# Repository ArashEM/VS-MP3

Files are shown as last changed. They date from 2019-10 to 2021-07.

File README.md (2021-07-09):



# Introduction

`VS1063` is an audio encoder/decoder from [VLSI solution](http://www.vlsi.fi/en/home.html). Base on VS1063 and STM32F1X, I'd designed a simple MP3 player. 

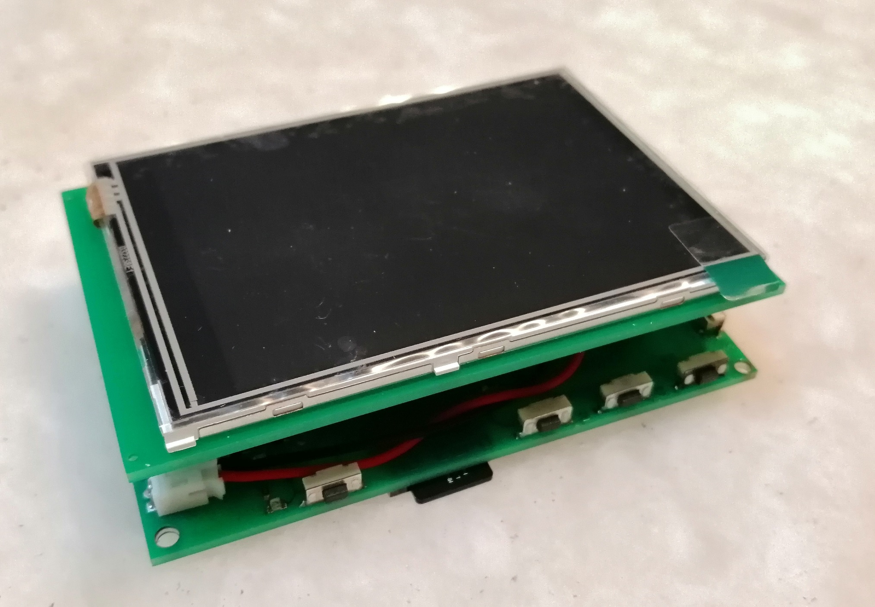
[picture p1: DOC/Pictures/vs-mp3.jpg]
MP3P-OFF


# Specification

Here is list of main element used in my MP3P project:

- `VS1063a` as MP3 / FLAC decoder
- `STM32F103RCT6` as main controller 
- Can be powered from USB and Li-ion battery (without interruption on exchange)
- `TPS62110QRSARQ1`  as switching regulator (3v7 to 3v3)
- `MAX1555EZK` Li-ion battery charger
- `LTC4412ES6` Power Path controller 
- `SDIO` 4bit connection (<u>which only 1bit got working</u>!)
- Header pin for LCD connection (Compatible with Raspberry Pi hats)

# Notes

Here is some important notes about this project

1. <u>There is an issue with SDIO and 4 bit connection</u>. I can **NOT** get 4 bit mode working. So I tried to deal with 1bit mode. The problem show it self when you are decoding **FLAC** format. because of SD card slow interface, music can get slow! 
2. I think I should use pull-ups in SDIO data pins. But I'm not sure and I didn't try it till now!
3. Codes is `FW` directory is simple demo application, which play everything in root directory of SD card.
4. Before any decision about this board, as good friend said: **Check it yourself** !
5. Finally ... Have fun ...

## File hierarchy 
- `FW`: includes Keil/Makefile based source code wihch is generated via `STM32CubeMx` and `FW_F1-V1.8.3`
- `HW`: includes schematic/pcb project 
  - `main`: MP3 player main board 
  - `dtr`: LCD and touch screen daughter board
- `DOC`: includes general documents about this project (e.g. datasheets and ...)
- `BOX`: includes related files for box and packaging

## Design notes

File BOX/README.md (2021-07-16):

# Introduction

Idea of  box comes from [Arvinpack](https://www.arvinpack.com/product/craft-prepared-box-keshoyi/). 

Their box is not manufactured form proper material. So designed and built something similar to it. (from _Fabriano  paper, 220 g/m2, 50x70_)

## Files

As I'm an electronic engineer so I'd designed box files with **Altium Designer**!

- `box.PcbDoc`: contains box cutout (_Thick_ lines should be cut, _Thin_ lines should be bent)
- `cover.PcbDoc`: contains cover cutout 
- `holder.PcbDoc`: contains board holder cutout

For each one, I've created `pdf` files which must be printed in actual size (`A4` for holder, `A2` for box and cover)

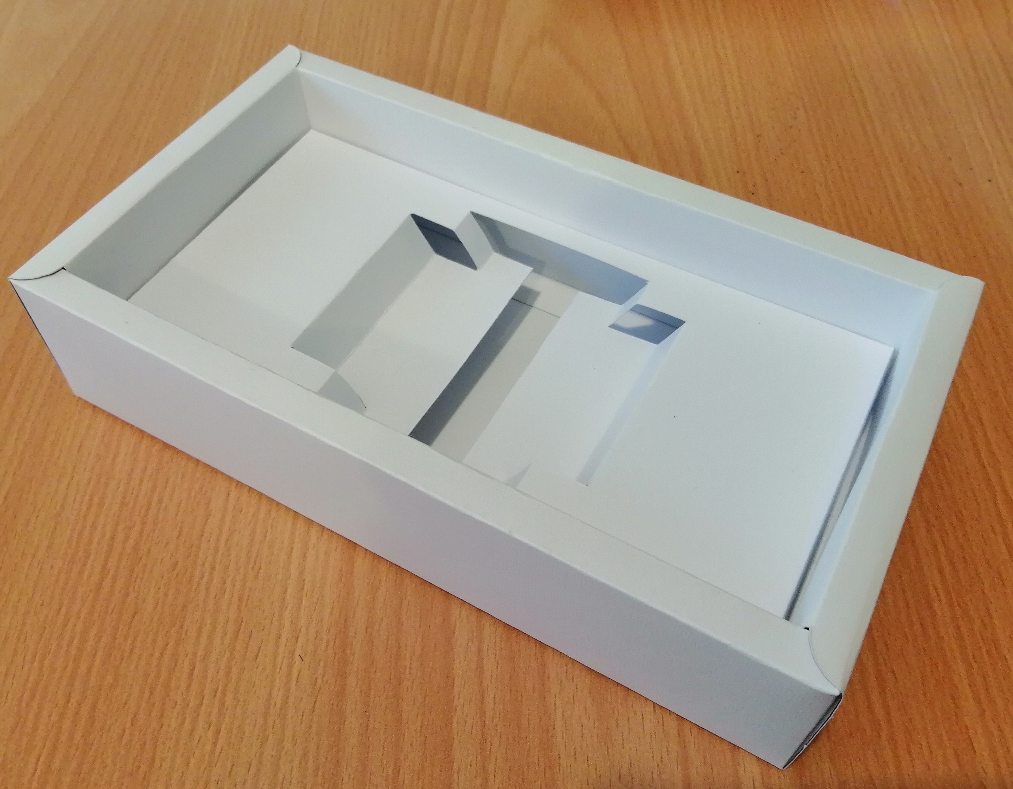
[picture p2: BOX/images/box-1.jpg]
box-1


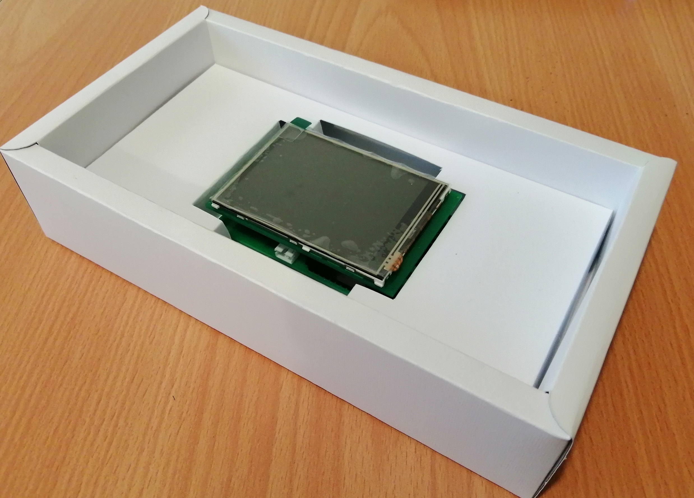
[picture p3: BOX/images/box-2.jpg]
box-2


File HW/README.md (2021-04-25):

# Introduction

This folder contains SCH/PCB files for VS-MP3 project
- `mian`: includes Altium project for main board.
- `dtr`: includes Altium project for LCD/Touch board.

# HW information 

This section includes all information you need about HW platform.  
Like pin assignment, crystal frequency and ...

## General 
- Used micro-controller: `STM32F103RCT6`
  - `HSE` crystal frequency: **8 Mhz**
  - `LSE` crystal frequency: **32.768 Khz**
- LCD controller: `ili9341` / `ili9486`
- Touch screen controller: `xpt2046`
- `VS1063a` crystal frequency: **12.288 Mhz**

## µC Pin assignment

Pin names are according to `STM32F103xC` datasheet, **Table 5**
- `Pin name`: came from micro-controller datasheet
- `Alias in Code`: In order to access a pin via `STM32 HAL GPIO API` you need `PORT` and `PIN`
  - `PORT` is the name in `Alias in Code` column appended to `_GPIO_Port`. (e.g. if Alias is `LED`, it's **port** name will be `LED_GPIO_Port`)
  - `PIN` is name in `Alias in Code` column appended to `_Pin`. (e.g. if Alias is `LED`, it's **pin** name will be `LED_Pin`)
  - As full example, we can toggle LED via `HAL_GPIO_TogglePin(LED_GPIO_Port,LED_Pin);`
- `Peripheral`: which peripheral is used via this pin 
- `Direction`: Pin direction and driver/input type
  - `OUT/PP`: push-pull output driver
  - `IN/PP`: pulled-up input
  - `IN/A`: analog input
  - `OUT/A`: analog output
  - `IN/AF`: input alternative function
  - `OUT/AF`: output alternative function
- `Description`: Some note about this pin (Active high/low, ...)

| Pin name  	| Alias in Code | Peripheral 		| Direction | Description 											|
| ---| ---| ---| ---| ---|
| `PC13` 	| `CHG`			| `GPIO`			| `IN/PP`	| `CHG` pin of `MAX1555` 								|
| `PC0` 	| `ADC_BAT`		| `ADC1_IN10`		| `IN/A`	| Analog battery voltage equal to `0.28 x V-BAT` 		|
| `PC1` 	| `KEY1`		| `GPIO`			| `IN/PP`	| Push button 1 (`S3`) 									|
| `PC2`			| `KEY2`		| `GPIO`			| `IN/PP`	| Push button 2 (`S4`)									|
| `PC3`			| `KEY3`		| `GPIO`			| `IN/PP`	| Push button 3 (`S5`)									|
| `PA0`			| `KEY4`		| `GPIO`			| `IN/PP`	| Push button 4 (`S6`)									|
| `PA1`			| `LED`			| `GPIO`			| `OUT/PP`	| Green LED (`D6`)  									|
| `PA4`			| `VDAC`		| `DAC_OUT1`		| `OUT/A`	| Analog output (`HDR-PIN12`)							|
| `PA15`		| `PWR_EXT`		| `GPIO`			| `OUT/PP`	| Enable `3v3_EXT` supply in `HDR-PIN1`/`HDR-PIN17`		|
| `PB4`			| `REG_PG`		| `GPIO`			| `IN/PP`	| `PG` pin of `TPS62110QRSARQ1`							|
| `PB5`			| `REG_LBO`		| `GPIO`			| `IN/PP`	| `LBO` pin of `TPS62110QRSARQ1` (`LBI = 0.35 x V-BAT`)	|
| `PB8`			| `REG_SYNC`	| `GPIO`			| `OUT/PP`	| `SYNC` pin of `TPS62110QRSARQ1` (Optional connection)	|
| `PB9`			| `VBUS`		| `GPIO`			| `IN`		| Detect power on USB connector (`VBUS = 0.63 x V-USB`)	|
| `PC4`			| `xCS`			| `GPIO`			| `OUT/PP`	| `xCS` pin of `VS1063a`								|
| `PC5`			| `xDCS`		| `GPIO`			| `OUT/PP`	| `xDCS` pin of `VS1063a`								|
| `PB0`			| `DREQ`		| `GPIO/EXTI0_IRQn`	| `IN`		| `DREQ` pin of `VS1063a`								|
| `PB1`			| `xRST`		| `GPIO`			| `OUT/PP`	| `DREQ` pin of `VS1063a`								|
| `PA5`			| `SPI1_SCK`	| `SPI1/SCK`		| `OUT/AF`	| `SCLK` pin of `VS1063a`								|
| `PA6`			| `SPI1_MISO`	| `SPI1/MISO`		| `IN/AF`	| `SO` pin of `VS1063a`									|
| `PA7`			| `SPI1_MOSI`	| `SPI1/MOSI`		| `OUT/AF`	| `SI` pin of `VS1063a`									|
| `PB10`		| `LCD_DCX`		| `GPIO`			| `OUT/PP`	| `DCX` pin of `ili9341`(`HDR-PIN15`)					|
| `PB12`		| `LCD_CS`		| `GPIO/SPI2-NCS0`	| `OUT/PP`	| `CS` pin of `ili9341` (`HDR-PIN24`)					|
| `PC6`			| `LCD_RSTN`	| `GPIO`			| `OUT/PP`	| `RSTN` pin of `ili9341` (`HDR-PIN13`)					|
| `PB11`		| `TP_CS`		| `GPIO/SPI2-NCS1`	| `OUT/PP`	| `CS` pin of `xpt2046` (`HDR-PIN26`)					|
| `PC7`			| `TP_IRQ`		| `GPIO/EXTI7_IRQn`	| `IN`		| `IRQ` pin of `xpt2046` (`HDR-PIN11`)					|
| `PA8`			| `BL_PWM`		| `GPIO`			| `OUT/PP`	| Backlight PWM for LCD (`HDR-PIN7`)					|
| `PA13`		| `SWDIO`		| `SYSTEM`			| `N.A.`	| `SWDIO` pin of `STM32F103RCT6`						|
| `PA14`		| `SWCLK`		| `SYSTEM`			| `N.A.`	| `SWCLK` pin of `STM32F103RCT6`						|
| `PB3`			| `SD_CD`		| `GPIO`			| `IN/PP`	| SD card detect pin 									|
| `PC8`			| `SDIO_D0`		| `SDIO/D0`			| `AF`		| `D0` pin of SD card (SDIO works on in `1bit` mode)	|
| `PC9`			| `SDIO_D1`		| `SDIO/D1`			| `AF`		| `D1` pin of SD card	(**Not working yet**)			|
| `PC10`		| `SDIO_D2`		| `SDIO/D2`			| `AF`		| `D2` pin of SD card	(**Not working yet**)			|
| `PC11`		| `SDIO_D3`		| `SDIO/D3`			| `AF`		| `D3` pin of SD card	(**Not working yet**)			|
| `PC12`		| `SDIO_CK`		| `SDIO/CK`			| `OUT/AF`	| `CLK` pin of SD card									|
| `PD2`			| `SDIO_CMD`	| `SDIO/CMD`		| `OUT/AF`	| `CMD` pin of SD card									|
| `PB13`		| `SPI2_SCK`	| `SPI2/SCK`		| `OUT/AF`	| `SPI/CLK` for `ili9341`/`xpt2046` (`HDR-PIN23`)		|
| `PB15`		| `SPI2_MOSI`	| `SPI2/MOSI`		| `OUT/AF`	| `SPI/MOSI` for `ili9341`/`xpt2046` (`HDR-PIN19`)		|
| `PB14`		| `SPI2_MISO`	| `SPI2/MISO`		| `IN/AF`	| `SPI/MISO` for `ili9341`/`xpt2046` (`HDR-PIN21`)		|
| `PB6`			| `I2C1_SCL`	| `I2C1/SCL`		| `OUT/AF`	| `I2C/SCL` with 4.7k pull-up (`HDR-PIN5`)				|
| `PB7`			| `I2C1_SDA`	| `I2C1/SDA`		| `AF`		| `I2C/SDA` with 4.7k pull-up (`HDR-PIN3`)				|
| `BOOT0`		| `N.A.`		| `SYSTEM`			| `N.A.`	| pulled down to `GND` via 10K							|
| `PB2 (BOOT1)`	| `N.A.`		| `SYSTEM`			| `N.A.`	| pulled down to `GND` via 10K							|
| `PA2`			| `USART2_TX`	| `USART2/TX`		| `OUT/AF`	| optional connection for `RX` pin of `VS1063a`			|
| `PA3`			| `USART2_RX`	| `USART2/RX`		| `IN/AF`	| optional connection for `TX` pin of `VS1063a`			|
| `PA9`			| `USART1_TX`	| `USART1/TX`		| `OUT/AF`	| USART/Tx interface (`HDR-PIN8`)						|
| `PA10`		| `USART1_RX`	| `USART1/TX`		| `IN/AF`	| USART/Rx interface (`HDR-PIN10`)						|

## Header pin assignment

Here is table of `VS1063a` UART pin assignment (**P1**)

| Pin Num.  | Description |
| --- | --- |
|	**1**	| `GND`			|
|	**2**	| `VS-RX`		|
|	**3**	| `VS-TX`		|

Here is table of VS-MP3 main board header pin (**P2**)

| Description  	| Pin		| Pin		| Description 	|
|---|---|---|---|
| `3v3_EXT`		| **1**		|	**2**	| `5V0` (USB only)	|
| `I2C1_SDA`	| **3**		|	**4**	| `5V0` (USB only)	|
| `I2C1_SCL`	| **5**		|	**6**	| `GND`				|
| `BL_PWM` 		| **7**		|	**8**	| `USART1_TX`		|
| `GND`			| **9**		|	**10**	| `USART1_RX`		|
| `TP_IRQ`		| **11**	|	**12**	| `VDAC`			|
| `LCD_RSTN`	| **13**	|	**14**	| `GND`				|
| `LCD_DCX`		| **15**	|	**16**	| `N.C.`			|
| `3v3_EXT`		| **17**	|	**18**	| `N.C.`			|
| `SPI2_MOSI`	| **19**	|	**20**	| `GND`				|
| `SPI2_MISO`	| **21**	|	**22**	| `N.C.`			|
| `SPI2_SCK`	| **23**	|	**24**	| `LCD_CS`			|
| `GND`			| **25**	|	**26**	| `TP_CS`			|

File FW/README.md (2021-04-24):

# Introduction

This folder contains `VS-MP3P` firmware.  
In order to build this firmware you need at least one of following items

## Keil 
You need `Keil µVision V5.16.0.0` installed.
1. `git clone git@github.com:ArashEM/VS-MP3.git`
1. open project file in `FW/MDK-ARM/MP3P.uvprojx`
2. press `F7`
3. find hex/axf file in `FW/MDK-ARM/MP3P/MP3P.axf`

## GCC
You need `arm-none-eabi-gcc` and `GNU make` installed. 
1. `git clone git@github.com:ArashEM/VS-MP3.git`
2. `cd FW/ && make all`
3. find hex/bin file in `FW/build/MP3P.hex`

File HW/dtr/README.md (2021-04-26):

# Introduction

This folder contains SCH/PCB files for LCD daughter board 

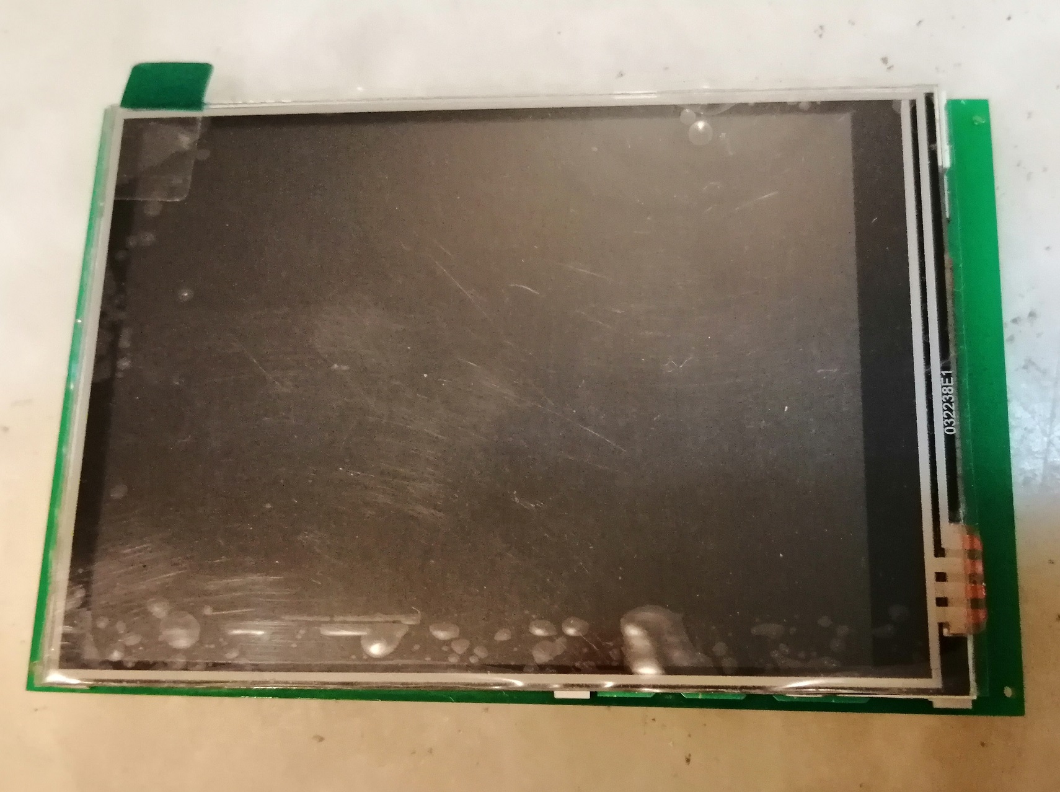
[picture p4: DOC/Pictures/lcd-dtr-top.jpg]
LCD-Top


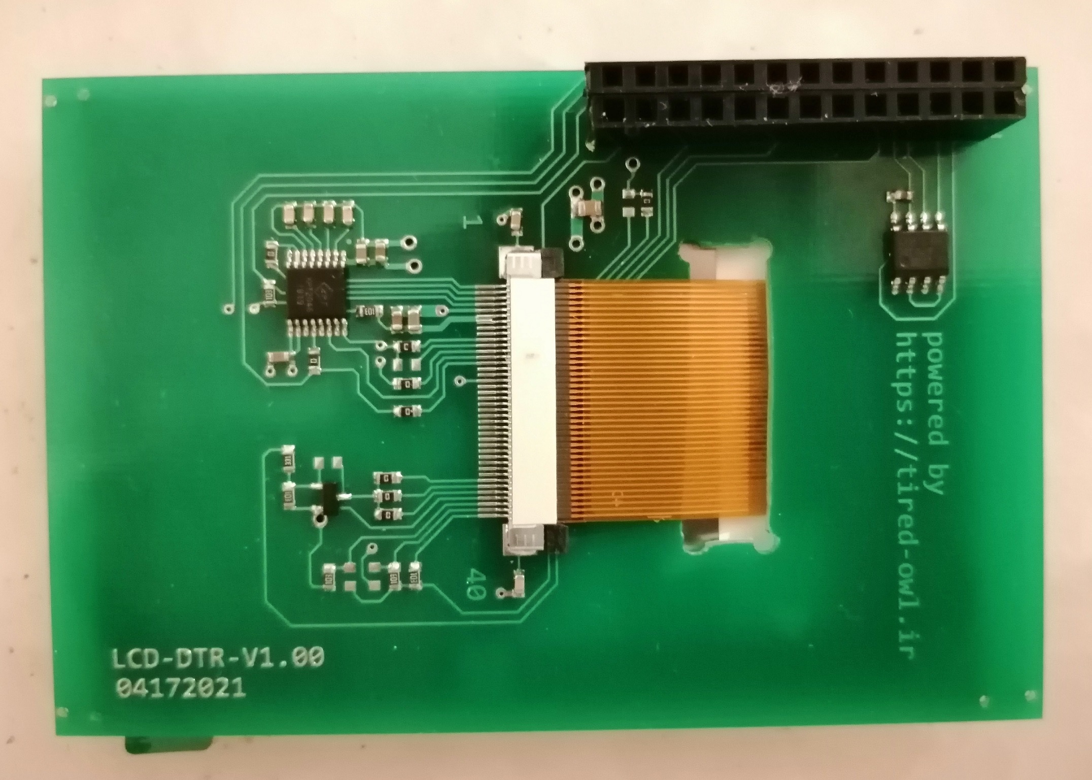
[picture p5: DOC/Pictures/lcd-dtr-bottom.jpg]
LCD-Bot


This board contains following items 
- **40pin-FPC** connector which is compatible with following LCDs
  - *ZJY320IT008*: 3.2 inch *240x320* dots matrix TFT LCD module with `ili9341` controller
  - *ZJY350IT006*: 3.5 inch *320x480* dots matrix TFT LCD module with `ili9486` controller
- `xpt2046` touch screen controller (`ADS7843` can be used too)
- `AT24C512C-SSHD-T` eeprom for some permanent information 

# 3.5/3.2 inch LCD support

According to datasheets of *ZJY320IT008* and *ZJY350IT006* they are **NOT** exactly pin-to-pin compatible!
There is a **subtle** difference which is handled in SCH/PCB via `0R` options. 
For simplicity, I just document the difference. 

| Pin			| *ZJY320IT008* function 		| *ZJY350IT006* function 		|
|---|---|---|
| **10** 		| `SCK` (SPI) / `RS` (Parallel)	| `D/CX`(SPI)			 		|
| **11**		| `D/CX`(SPI) / `WR` (Parallel) | `SCK` (SPI) / `RS` (Parallel) |
| **38/39/40**	| `b011` 4-wire / 8-bit / SPI	| `b111` 4-wire SPI				|

This difference is handled via `R9`/`R17`/`R18`/`R19`/`R20`/`R21` in daughter

| Rx 	| *ZJY320IT008* | *ZJY350IT006* |
|---|---|---|
| `R9`	|	`DNP`		|	`10K`		|
| `R17`	|	`10K`		|	`DNP`		|
| `R18`	|	`0R`		|	`DNP`		|
| `R19`	|	`DNP`		|	`0R`		|
| `R20`	|	`DNP`		|	`0R`		|
| `R21`	|	`0R`		|	`DNP`		|

For more information please check `DOC/datasheets/lcd`

# BOM

| Designator 							| 	Quantity	|	Value			|	Footprint	|
|---|---|---|---|
| `C1`,`C2`,`C8`,`C9`,`C10`,`C11`,`C12`	|	**7**		| `100nF`			|	*0603*		|
| `C3`									|	**1**		| `10uF`			|	*0603*		|
| `C4`,`C5`,`C6`,`C7`					|	**4**		| `10nF`			|	*0603*		|
| `C13`									|	**1**		| `10uF`			|	*0805*		|
| `R1`,`R2`,`R7`,`R8`,`R13`,`R17`		|	**6**		| `10K` 			|	*0603*		|
| `R3`,`R4`,`R5`,`R6`,`R18`,`R21`		|	**6**		| `0R`				|	*0603*		|
| `R9`,`R12`							|	**2**		| `10K_DNP`			|	*0603*		|
| `R10`,`R19`,`R20`						|	**3**		| `0R_DNP`			|	*0603*		|
| `R11`									|	**1**		| `330R`			|	*0603*		|
| `R14`,`R15`,`R16`						|	**3**		| `10R`				|	*0603*		|
| `Q1`									|	**1**		| `IRLML2803TRPBF` 	|	*SOT23*		|
| `U1`									|	**1**		| `xpt2046`			| 	*TSSOP16*	|
| `U2`									|	**1**		| `AT24C512C-SSHD-T`|	*8S1_N*		|
| `LCD1`								|	**1**		| `FPC` 			| *40pin-0.5mm*	|
| `P1`									|	**1**		| `HDR2X13`			| *2x13 100mil*	|

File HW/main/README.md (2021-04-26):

# Introduction

Here is *VS-MP3* main board

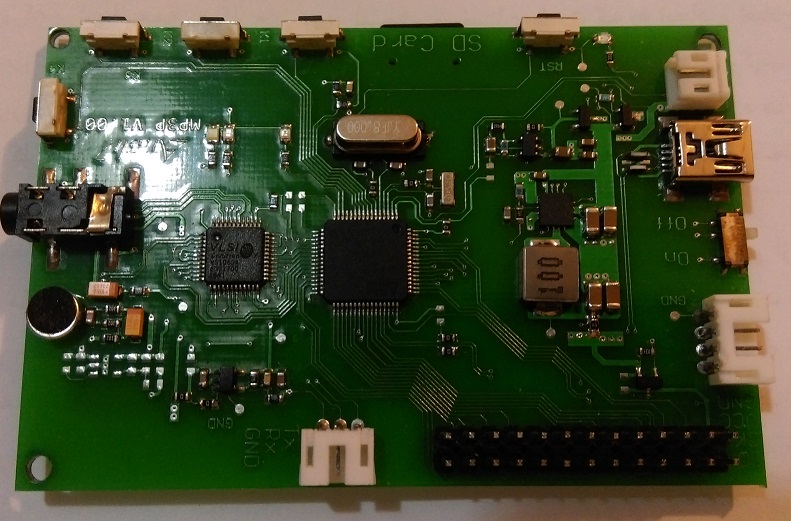
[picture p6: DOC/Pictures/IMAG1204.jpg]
TOP


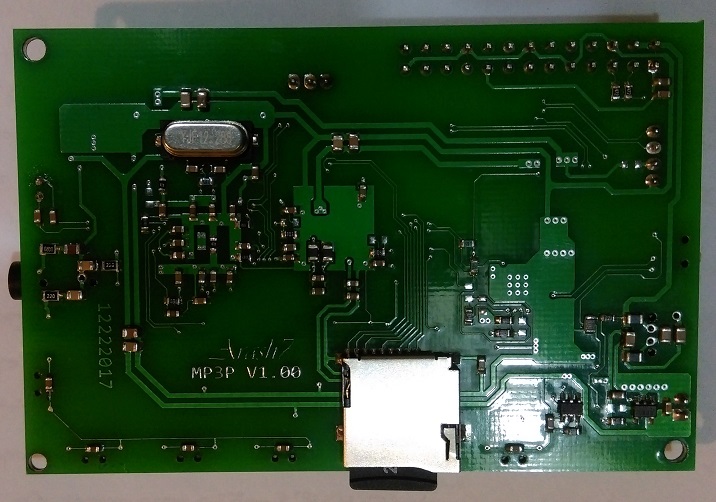
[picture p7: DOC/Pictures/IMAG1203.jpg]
BOT


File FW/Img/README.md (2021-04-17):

# Images

This folder contains original images which are used in projects.

They are used in project source code via **Segger bitmap Converter** with same name. (eg. `moon.c` is bitmap converted of `moon.jpg` )

## specification 

According to LCD interface and color depth, image are converted via _565_ color depth (_Red_: `5 bit`, _Green_: `6 bit` , _Blue_: `5 bit` ) 

## Usage

Here is list of image and there use case in project 

1. `moon.jpg`
2. `tired-owl.png`

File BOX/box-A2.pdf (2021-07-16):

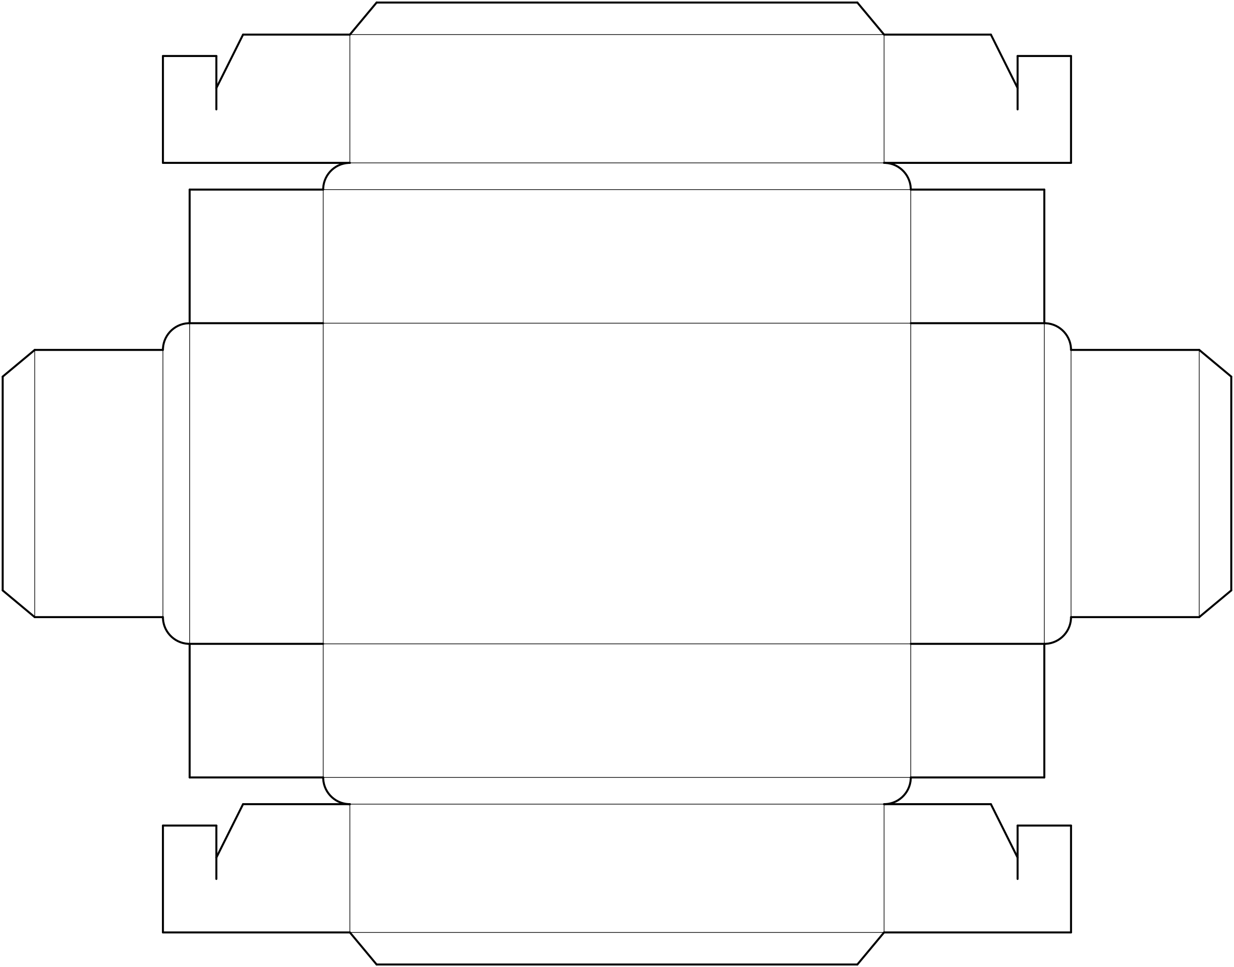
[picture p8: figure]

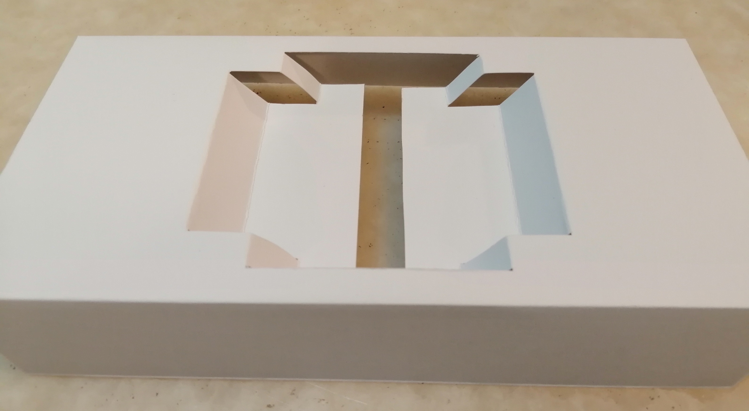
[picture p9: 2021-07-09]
BOX/images/holder-2.jpg

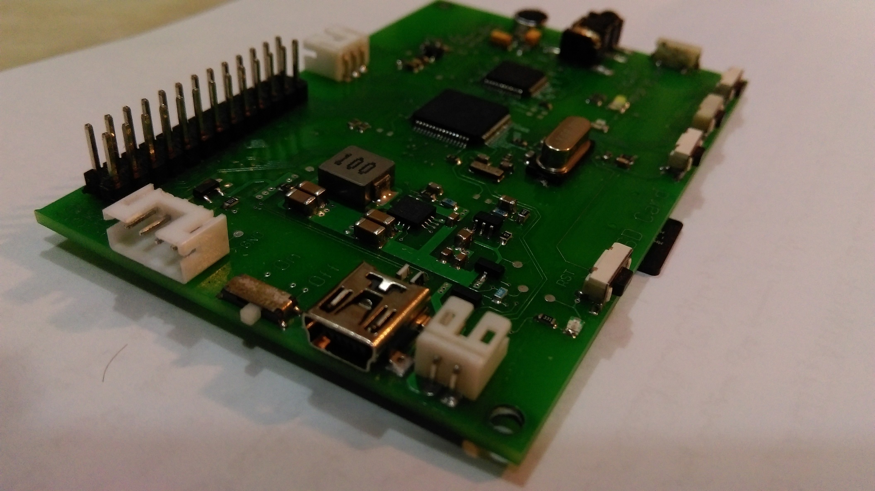
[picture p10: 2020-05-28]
DOC/Pictures/IMAG1206.jpg

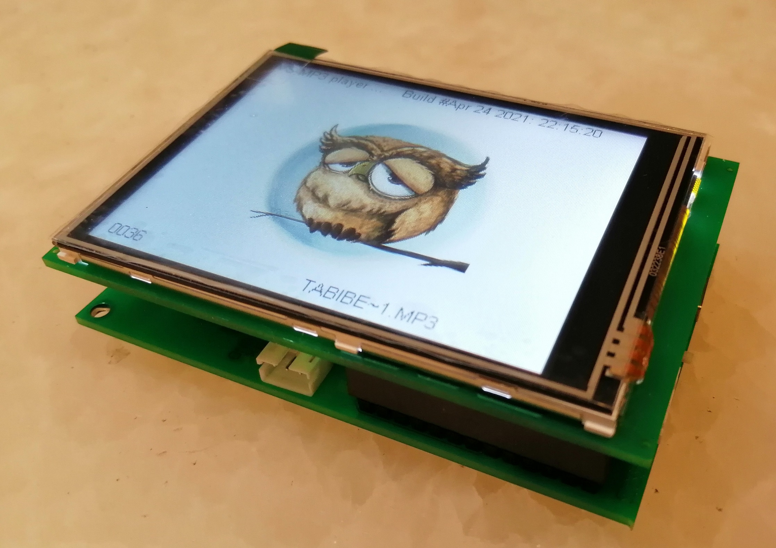
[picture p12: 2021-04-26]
DOC/Pictures/vs-mp3-on.jpg

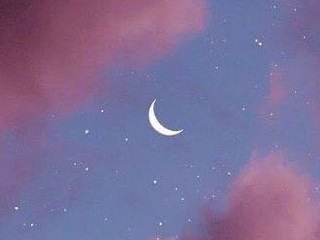
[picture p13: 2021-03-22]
FW/Img/moon.jpg

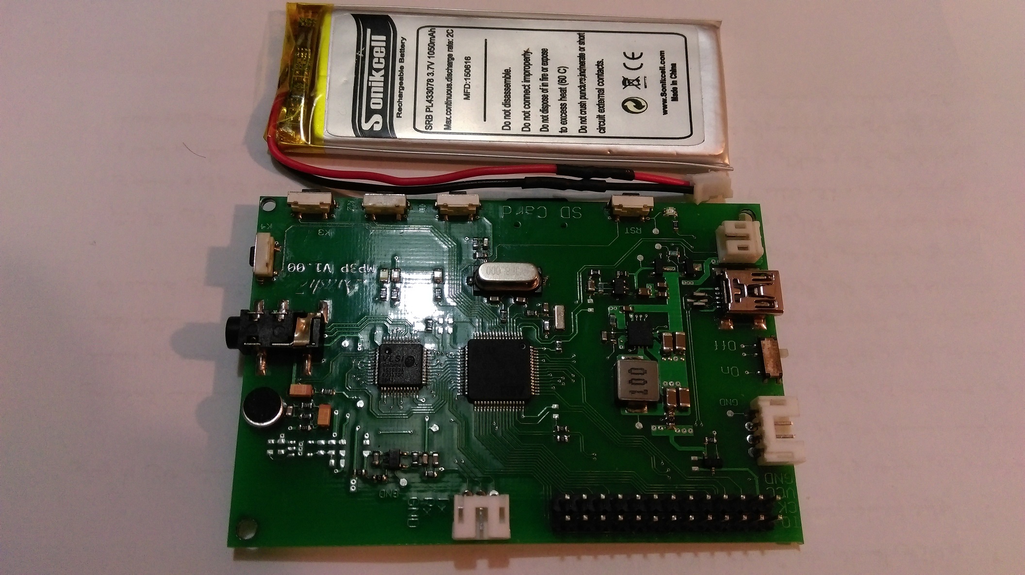
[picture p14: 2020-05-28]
DOC/Pictures/IMAG1216.jpg

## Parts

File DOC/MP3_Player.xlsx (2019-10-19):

Availability | Designator | Quantity | Value | Footprint | Description | LibRef
Yes | C1, C3, C12, C13, C21, C26, C28, C29, C30, C31, C36, C37, C38, C40, C41, C42, C52, C54, C56, C57, C58, C59, C60, C65, C66, C67, C68, C69 | 28 | 100nF | 0603PKG | Capacitor, Capacitor, Capacitor, Capacitor, Capacitor (Semiconductor SIM Model), Capacitor (Semiconductor SIM Model), Capacitor (Semiconductor SIM Model), Capacitor (Semiconductor SIM Model), Capacitor (Semiconductor SIM Model), Capacitor (Semiconductor SIM Model), Capacitor (Semiconductor SIM Model), Capacitor (Semiconductor SIM Model), Capacitor (Semiconductor SIM Model), Capacitor (Semiconductor SIM Model), Capacitor (Semiconductor SIM Model), Capacitor (Semiconductor SIM Model), Capacitor (Semiconductor SIM Model), Capacitor (Semiconductor SIM Model), Capacitor (Semiconductor SIM Model), Capacitor (Semiconductor SIM Model), Capacitor (Semiconductor SIM Model), Capacitor (Semiconductor SIM Model), Capacitor (Semiconductor SIM Model), Capacitor (Semiconductor SIM Model), Capacitor (Semiconductor SIM Model), Capacitor (Semiconductor SIM Model), Capacitor (Semiconductor SIM Model), Capacitor | Cap, Cap, Cap, Cap, Cap Semi, Cap Semi, Cap Semi, Cap Semi, Cap Semi, Cap Semi, Cap Semi, Cap Semi, Cap Semi, Cap Semi, Cap Semi, Cap Semi, Cap Semi, Cap Semi, Cap Semi, Cap Semi, Cap Semi, Cap Semi, Cap Semi, Cap Semi, Cap Semi, Cap Semi, Cap Semi, Cap
Javan | C2, C5, C8, C11, C19, C35, C45, C48, C53 | 9 | 1uF | 0603PKG | Capacitor, Capacitor, Capacitor, Capacitor, Capacitor (Semiconductor SIM Model), Capacitor (Semiconductor SIM Model), Capacitor (Semiconductor SIM Model), Capacitor (Semiconductor SIM Model), Capacitor (Semiconductor SIM Model) | Cap, Cap, Cap, Cap, Cap Semi, Cap Semi, Cap Semi, Cap Semi, Cap Semi
Javan | C4, C20, C25, C32, C39, C43, C55 | 7 | 10uF | 0603PKG | Capacitor, Capacitor (Semiconductor SIM Model), Capacitor (Semiconductor SIM Model), Capacitor (Semiconductor SIM Model), Capacitor (Semiconductor SIM Model), Capacitor (Semiconductor SIM Model), Capacitor (Semiconductor SIM Model) | Cap, Cap Semi, Cap Semi, Cap Semi, Cap Semi, Cap Semi, Cap Semi
Yes | C6, C7, C9, C71, C73, C75 | 6 | 100nF | C0805 | Capacitor, Capacitor, Capacitor, Capacitor (Semiconductor SIM Model), Capacitor (Semiconductor SIM Model), Capacitor (Semiconductor SIM Model) | Cap, Cap, Cap, Cap Semi, Cap Semi, Cap Semi
Javan | C10, C22, C27 | 3 | 10nF | 0603PKG | Capacitor (Semiconductor SIM Model) | Cap Semi
Javan | C14, C15 | 2 | 10uF | C1206 | Capacitor (Semiconductor SIM Model) | Cap Semi
Javan | C16, C61, C62, C63, C64 | 5 | 10pF | 0603PKG | Capacitor (Semiconductor SIM Model), Capacitor, Capacitor, Capacitor, Capacitor | Cap Semi, Cap, Cap, Cap, Cap
Javan | C17, C18 | 2 | 22uF | C1206 | Capacitor (Semiconductor SIM Model) | Cap Semi
Javan | C23, C24 | 2 | 4.7uF | C0805 | Capacitor (Semiconductor SIM Model) | Cap Semi
Javan | C33, C34 | 2 | 33pF | 0603PKG | Capacitor | Cap
Yes | C44, C47 | 2 | 10uF | 3216X18N | Polarized Capacitor (Surface Mount) | Cap Pol3
Javan | C46 | 1 | 100pF | 0603PKG | Capacitor (Semiconductor SIM Model) | Cap Semi
Yes | C49 | 1 | 47n | C0805 | Capacitor (Semiconductor SIM Model) | Cap Semi
Yes | C50, C51 | 2 | 10n | C0805 | Capacitor (Semiconductor SIM Model) | Cap Semi
Javan | C70, C72, C74 | 3 | 10uF | C0805 | Capacitor (Semiconductor SIM Model) | Cap Semi
Javan | D1, D4, D5, D6 | 4 |  | C0805 | Typical INFRARED GaAs LED | LED0
Yes | J1 | 1 |  | Audio Jack |  | Audio Jack
Yes | L1, L2, L4, L5 | 4 | 10mH | C0805 | Inductor | Inductor
Yes | L3 | 1 | 10uH | CAPM3216X18N | Magnetic-Core Inductor | Inductor Iron
Javan | MK1 | 1 |  | Microphone | Microphone | Mic2
Yes | P1 | 1 |  | XH_3Pin_RA | Header, 3-Pin | Header 3
Yes | P2 | 1 |  | HDR2X13 | Header, 13-Pin, Dual row | Header 13X2
Yes | P3 | 1 |  | XH_4Pin_RA | Header, 4-Pin | Header 4
Yes | P4 | 1 |  | XH_2Pin_RA | Header, 2-Pin | Header 2
Yes | P5 | 1 |  | Mini USB |  | Mini USB
Yes | Q1, Q2, Q3 | 3 |  | SOT23 | P-Channel Power MOSFET | PMOS-2
Yes | R2, R3, R4, R8, R9, R24, R27, R29, R44, R58 | 10 | 0R_DNP | 0603PKG | Resistor, Resistor, Resistor, Resistor, Semiconductor Resistor, Resistor, Resistor, Resistor, Resistor, Resistor | Res1, Res1, Res1, Res1, Res Semi, Res1, Res1, Res1, Res1, Res1
Javan | R5, R17, R66, R70 | 4 | 10K | 0603PKG | Resistor, Semiconductor Resistor, Resistor, Resistor | Res1, Res Semi, Res1, Res1
Javan | R6, R7 | 2 | 4.7K | 0603PKG | Resistor | Res1
Yes | R10, R25, R30, R31, R33, R37, R46, R47, R59, R60, R62 | 11 | 0R | 0603PKG | Semiconductor Resistor, Resistor, Resistor, Resistor, Resistor, Resistor, Resistor, Resistor, Resistor, Resistor, Resistor | Res Semi, Res1, Res1, Res1, Res1, Res1, Res1, Res1, Res1, Res1, Res1
Javan | R11, R50, R51, R68 | 4 | 330 | 0603PKG | Semiconductor Resistor | Res Semi
Javan | R12 | 1 | 27K | 0603PKG | Semiconductor Resistor | Res Semi
Javan | R13 | 1 | 100K_1% | 0603PKG | Semiconductor Resistor | Res Semi
Javan | R14 | 1 | 47K | 0603PKG | Semiconductor Resistor | Res Semi
Javan | R15 | 1 | 39K_1% | 0603PKG | Semiconductor Resistor | Res Semi
KA | R16 | 1 | 470K (390K) | 0603PKG | Semiconductor Resistor | Res Semi
Yes | R18 | 1 | 0R | C0805 | Resistor | Res1
KA | R19 | 1 | 180K | 0603PKG | Resistor | Res1
Javan | R20, R40, R41, R48, R49, R57 | 6 | 100K | 0603PKG | Resistor | Res1
KA | R21, R22, R42 | 3 | 1M | 0603PKG | Resistor | Res1
KA | R23 | 1 | 560K | 0603PKG | Resistor | Res1
KA | R26 | 1 | 300K | 0603PKG | Resistor | Res1
Javan | R28, R65, R67 | 3 | 10K_DNP | 0603PKG | Resistor | Res1
KA | R32 | 1 | 28K | 0603PKG | Resistor | Res1
KA | R34 | 1 | 56.2K | 0603PKG | Resistor | Res1
KA | R35 | 1 | 301K (300K) | 0603PKG | Resistor | Res1
KA | R36 | 1 | 169K (180K || 2.7M) | 0603PKG | Resistor | Res1
KA | R38 | 1 | 52.3K (56.2K) | 0603PKG | Resistor | Res1
KA | R39 | 1 | 30.1K (100K || 47K) | 0603PKG | Resistor | Res1
Javan | R43, R45, R52, R53 | 4 | 1K | 0603PKG | Resistor | Res1
Javan | R54 | 1 | 10R | C0805 | Resistor | Res1
Javan | R55, R56 | 2 | 20R | C0805 | Resistor | Res1
KA | R61 | 1 | 1.5K_DNP | 0603PKG | Resistor | Res1
* | R63, R64 | 2 | 5R | 0603PKG | Resistor | Res1
Yes | S1 | 1 |  | Slide switch | SPDT Subminiature Toggle Switch, Right Angle Mounting, Vertical Actuation | SW-SPDT
Yes | S2, S3, S4, S5, S6 | 5 |  | SMD push button | Switch | SW-PB
Yes | SD1 | 1 |  | MicroSD socket |  | MicroSD_holder
Yes | TP1, TP2, TP3, TP4, TP5, TP6, TP7, TP8, TP9 | 9 |  | TP_15 |  | Test Point
Yes | U1, U5, U6, U7 | 4 |  | SOT23-5 | 1-Cell Li+ Battery Chargers, TPS736xx Cap-Free, NMOS, 400-mA Low-Dropout Regulator with Reverse Current Protection, TPS763 Low-Power 150-mA Low-Dropout Linear Regulators, TPS736xx Cap-Free, NMOS, 400-mA Low-Dropout Regulator with Reverse Current Protection | MAX1555, TPS73601, TPS76301, TPS73601
Javan | U2 | 1 |  | SOT457 | TVS Zener | PRTR5V0U2D
Yes | U3 | 1 |  | SOT23-6 | Low Loss PowerPath™ Controller in ThinSOT | LTC4412
Yes | U4 | 1 | TPS62110 | QFN16-4*4*0.65 | 17-V, 1.5-A, SYNCHRONOUS STEP-DOWN CONVERTER | TPS62110
Yes | U8 | 1 |  | LQFP48 | Audion Codec | VS1063
Yes | U9 | 1 |  | LQFP64 | ARM Cortex-M3 32-bit MCU, 256 KB Flash, 48 KB Internal RAM, 51 I/Os, 64-pin LQFP, -40 to 85 degC, Tray | STM32F103RCT6
Javan | Y1 | 1 | 12.288Mhz | SMD_Crystal | Crystal Oscillator | XTAL
Javan | Y2 | 1 | 8Mhz | SMD_Crystal | Crystal Oscillator | XTAL
Javan | Y3 | 1 | 32.768Khz | CM415 | Crystal Oscillator CM415-32.768kHz | XTAL
KA- | R16 | 1 | 470K (390K) | 0603PKG | Semiconductor Resistor | Res Semi
KA- | R19 | 1 | 180K | 0603PKG | Resistor | Res1
KA- | R21, R22, R42 | 3 | 1M | 0603PKG | Resistor | Res1
KA- | R23 | 1 | 560K | 0603PKG | Resistor | Res1
KA- | R26 | 1 | 300K | 0603PKG | Resistor | Res1
KA- | R32 | 1 | 28K | 0603PKG | Resistor | Res1
KA- | R34 | 1 | 56.2K | 0603PKG | Resistor | Res1
KA- | R35 | 1 | 301K (300K) | 0603PKG | Resistor | Res1
KA- | R36 | 1 | 169K (180K || 2.7M) | 0603PKG | Resistor | Res1
KA- | R38 | 1 | 52.3K (56.2K) | 0603PKG | Resistor | Res1
KA- | R39 | 1 | 30.1K (100K || 47K) | 0603PKG | Resistor | Res1
KA- | R61 | 1 | 1.5K_DNP | 0603PKG | Resistor | Res1
KA |  |  | 2.7M

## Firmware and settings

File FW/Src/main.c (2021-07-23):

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
/* Includes ------------------------------------------------------------------*/
#include "main.h"
#include "cmsis_os.h"
#include "adc.h"
#include "crc.h"
#include "dac.h"
#include "dma.h"
#include "fatfs.h"
#include "i2c.h"
#include "sdio.h"
#include "spi.h"
#include "usart.h"
#include "usb_device.h"
#include "gpio.h"

/* USER CODE BEGIN Includes */
#include "vs10xx.h"
#include "misc_fatfs.h"
#include <string.h>
#include <stdio.h>
#include "ili9340.h"
#include "WM.h"
#include "mp3_player.h"
#include "debug.h"
/* USER CODE END Includes */


/* USER CODE BEGIN PV */
extern volatile GUI_TIMER_TIME 	OS_TimeMS;
/* USER CODE END PV */

void SystemClock_Config(void);
void MX_FREERTOS_Init(void);
/**
  * @brief  The application entry point.
  * @retval int
  */
int main(void)
{
  /* MCU Configuration--------------------------------------------------------*/

  /* Reset of all peripherals, Initializes the Flash interface and the Systick. */
  HAL_Init();

  /* Configure the system clock */
  SystemClock_Config();

  /* USER CODE BEGIN SysInit */
#if (configUSE_TRACE_FACILITY == 1)
	vTraceEnable(TRC_START);
#endif
  /* USER CODE END SysInit */

  /* Initialize all configured peripherals */
  MX_GPIO_Init();
  MX_DMA_Init();
  MX_USART2_UART_Init();
  MX_DAC_Init();
  MX_SPI1_Init();
  MX_ADC1_Init();
  MX_SDIO_SD_Init();
  MX_I2C1_Init();
  MX_SPI2_Init();
  MX_FATFS_Init();
  MX_CRC_Init();
  MX_USART1_UART_Init();
  /* USER CODE BEGIN 2 */
	HAL_NVIC_SetPriorityGrouping(NVIC_PRIORITYGROUP_4);
	vsmp3_init(NULL);
  /* USER CODE END 2 */

  /* Call init function for freertos objects (in freertos.c) */
  MX_FREERTOS_Init();
  /* Start scheduler */
  osKernelStart();

  /* We should never get here as control is now taken by the scheduler */
  /* Infinite loop */
  /* USER CODE BEGIN WHILE */
  while (1)
  {
    /* USER CODE END WHILE */

    /* USER CODE BEGIN 3 */
  }
  /* USER CODE END 3 */
}

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
 /**
  * @brief  Period elapsed callback in non blocking mode
  * @note   This function is called  when TIM1 interrupt took place, inside
  * HAL_TIM_IRQHandler(). It makes a direct call to HAL_IncTick() to increment
  * a global variable "uwTick" used as application time base.
  * @param  htim : TIM handle
  * @retval None
  */
void HAL_TIM_PeriodElapsedCallback(TIM_HandleTypeDef *htim)
{
  if (htim->Instance == TIM1) {
    HAL_IncTick();
  }
  /* USER CODE BEGIN Callback 1 */
	if (htim->Instance == TIM1) {
    OS_TimeMS++;
  }
  /* USER CODE END Callback 1 */
}

/**
  * @brief  This function is executed in case of error occurrence.
  * @retval None
  */		
void Error_Handler(void)
{
  /* USER CODE BEGIN Error_Handler_Debug */
  /* User can add his own implementation to report the HAL error return state */
	debug_print("error-handler:\r\n");
  /* USER CODE END Error_Handler_Debug */
}

#ifdef  USE_FULL_ASSERT
/**
  * @brief  Reports the name of the source file and the source line number
  *         where the assert_param error has occurred.
  * @param  file: pointer to the source file name
  * @param  line: assert_param error line source number
  * @retval None
  */
void assert_failed(uint8_t *file, uint32_t line)
{
  /* USER CODE BEGIN 6 */
  /* User can add his own implementation to report the file name and line number,
     tex: printf("Wrong parameters value: file %s on line %d\r\n", file, line) */
  /* USER CODE END 6 */
}
#endif /* USE_FULL_ASSERT */

/************************ (C) COPYRIGHT STMicroelectronics *****END OF FILE****/

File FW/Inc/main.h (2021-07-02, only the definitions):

#define CHG_Pin GPIO_PIN_13
#define CHG_GPIO_Port GPIOC
#define ADC_BAT_Pin GPIO_PIN_0
#define ADC_BAT_GPIO_Port GPIOC
#define KEY1_Pin GPIO_PIN_1
#define KEY1_GPIO_Port GPIOC
#define KEY1_EXTI_IRQn EXTI1_IRQn
#define KEY2_Pin GPIO_PIN_2
#define KEY2_GPIO_Port GPIOC
#define KEY2_EXTI_IRQn EXTI2_IRQn
#define KEY3_Pin GPIO_PIN_3
#define KEY3_GPIO_Port GPIOC
#define KEY3_EXTI_IRQn EXTI3_IRQn
#define KEY4_Pin GPIO_PIN_0
#define KEY4_GPIO_Port GPIOA
#define LED_Pin GPIO_PIN_1
#define LED_GPIO_Port GPIOA
#define VDAC_Pin GPIO_PIN_4
#define VDAC_GPIO_Port GPIOA
#define xCS_Pin GPIO_PIN_4
#define xCS_GPIO_Port GPIOC
#define xDCS_Pin GPIO_PIN_5
#define xDCS_GPIO_Port GPIOC
#define DREQ_Pin GPIO_PIN_0
#define DREQ_GPIO_Port GPIOB
#define DREQ_EXTI_IRQn EXTI0_IRQn
#define xRST_Pin GPIO_PIN_1
#define xRST_GPIO_Port GPIOB
#define LCD_DCX_Pin GPIO_PIN_10
#define LCD_DCX_GPIO_Port GPIOB
#define TP_CS_Pin GPIO_PIN_11
#define TP_CS_GPIO_Port GPIOB
#define LCD_CS_Pin GPIO_PIN_12
#define LCD_CS_GPIO_Port GPIOB
#define LCD_RSTN_Pin GPIO_PIN_6
#define LCD_RSTN_GPIO_Port GPIOC
#define TP_IRQ_Pin GPIO_PIN_7
#define TP_IRQ_GPIO_Port GPIOC
#define BL_PWM_Pin GPIO_PIN_8
#define BL_PWM_GPIO_Port GPIOA
#define SWDIO_Pin GPIO_PIN_13
#define SWDIO_GPIO_Port GPIOA
#define SWCLK_Pin GPIO_PIN_14
#define SWCLK_GPIO_Port GPIOA
#define PWR_EXT_Pin GPIO_PIN_15
#define PWR_EXT_GPIO_Port GPIOA
#define SD_CD_Pin GPIO_PIN_3
#define SD_CD_GPIO_Port GPIOB
#define REG_PG_Pin GPIO_PIN_4
#define REG_PG_GPIO_Port GPIOB
#define REG_LBO_Pin GPIO_PIN_5
#define REG_LBO_GPIO_Port GPIOB
#define REG_SYNC_Pin GPIO_PIN_8
#define REG_SYNC_GPIO_Port GPIOB
#define VBUS_Pin GPIO_PIN_9
#define VBUS_GPIO_Port GPIOB

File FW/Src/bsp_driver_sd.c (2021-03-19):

/**
 ******************************************************************************
  * @file    bsp_driver_sd.c for F1 (based on stm3210e_eval_sd.c)
 * @brief   This file includes a generic uSD card driver.
 *          To be completed by the user according to the board used for the project.
 * @note    Some functions generated as weak: they can be overridden by
 *          - code in user files
 *          - or BSP code from the FW pack files
 *          if such files are added to the generated project (by the user).
 ******************************************************************************
  * @attention
  *
  * <h2><center>&copy; Copyright (c) 2021 STMicroelectronics.
  * All rights reserved.</center></h2>
  *
  * This software component is licensed by ST under Ultimate Liberty license
  * SLA0044, the "License"; You may not use this file except in compliance with
  * the License. You may obtain a copy of the License at:
  *                             www.st.com/SLA0044
  *
 ******************************************************************************
 */

#ifdef OLD_API
/* kept to avoid issue when migrating old projects. */
#else
/* USER CODE BEGIN FirstSection */
/* can be used to modify / undefine following code or add new definitions */
/* USER CODE END FirstSection */
/* Includes ------------------------------------------------------------------*/
#include "bsp_driver_sd.h"

/* Extern variables ---------------------------------------------------------*/

extern SD_HandleTypeDef hsd;

/* USER CODE BEGIN BeforeInitSection */
/* can be used to modify / undefine following code or add code */
/* USER CODE END BeforeInitSection */
/**
  * @brief  Initializes the SD card device.
  * @retval SD status
  */
__weak uint8_t BSP_SD_Init(void)
{
  uint8_t sd_state = MSD_OK;
  /* Check if the SD card is plugged in the slot */
  if (BSP_SD_IsDetected() != SD_PRESENT)
  {
    return MSD_ERROR;
  }
  /* HAL SD initialization */
  sd_state = HAL_SD_Init(&hsd);

  return sd_state;
}
/* USER CODE BEGIN AfterInitSection */
/* can be used to modify previous code / undefine following code / add code */
/* USER CODE END AfterInitSection */

/* USER CODE BEGIN InterruptMode */
/**
  * @brief  Configures Interrupt mode for SD detection pin.
  * @retval Returns 0
  */
__weak uint8_t BSP_SD_ITConfig(void)
{  
  /* Code to be updated by the user or replaced by one from the FW pack (in a stmxxxx_sd.c file) */
  
  return (uint8_t)0;
}

/** @brief  SD detect IT treatment
  */
__weak void BSP_SD_DetectIT(void)
{
  /* Code to be updated by the user or replaced by one from the FW pack (in a stmxxxx_sd.c file) */
}
/* USER CODE END InterruptMode */

/* USER CODE BEGIN BeforeReadBlocksSection */
/* can be used to modify previous code / undefine following code / add code */
/* USER CODE END BeforeReadBlocksSection */
/**
  * @brief  Reads block(s) from a specified address in an SD card, in polling mode.
  * @param  pData: Pointer to the buffer that will contain the data to transmit
  * @param  ReadAddr: Address from where data is to be read
  * @param  NumOfBlocks: Number of SD blocks to read
  * @param  Timeout: Timeout for read operation
  * @retval SD status
  */
__weak uint8_t BSP_SD_ReadBlocks(uint32_t *pData, uint32_t ReadAddr, uint32_t NumOfBlocks, uint32_t Timeout)
{
  uint8_t sd_state = MSD_OK;

  if (HAL_SD_ReadBlocks(&hsd, (uint8_t *)pData, ReadAddr, NumOfBlocks, Timeout) != HAL_OK)
  {
    sd_state = MSD_ERROR;
  }

  return sd_state;
}

/* USER CODE BEGIN BeforeWriteBlocksSection */
/* can be used to modify previous code / undefine following code / add code */
/* USER CODE END BeforeWriteBlocksSection */
/**
  * @brief  Writes block(s) to a specified address in an SD card, in polling mode.
  * @param  pData: Pointer to the buffer that will contain the data to transmit
  * @param  WriteAddr: Address from where data is to be written
  * @param  NumOfBlocks: Number of SD blocks to write
  * @param  Timeout: Timeout for write operation
  * @retval SD status
  */
__weak uint8_t BSP_SD_WriteBlocks(uint32_t *pData, uint32_t WriteAddr, uint32_t NumOfBlocks, uint32_t Timeout)
{
  uint8_t sd_state = MSD_OK;

  if (HAL_SD_WriteBlocks(&hsd, (uint8_t *)pData, WriteAddr, NumOfBlocks, Timeout) != HAL_OK)
  {
    sd_state = MSD_ERROR;
  }

  return sd_state;
}

/* USER CODE BEGIN BeforeReadDMABlocksSection */
/* can be used to modify previous code / undefine following code / add code */
/* USER CODE END BeforeReadDMABlocksSection */
/**
  * @brief  Reads block(s) from a specified address in an SD card, in DMA mode.
  * @param  pData: Pointer to the buffer that will contain the data to transmit
  * @param  ReadAddr: Address from where data is to be read
  * @param  NumOfBlocks: Number of SD blocks to read
  * @retval SD status
  */
__weak uint8_t BSP_SD_ReadBlocks_DMA(uint32_t *pData, uint32_t ReadAddr, uint32_t NumOfBlocks)
{
  uint8_t sd_state = MSD_OK;

  /* Read block(s) in DMA transfer mode */
  if (HAL_SD_ReadBlocks_DMA(&hsd, (uint8_t *)pData, ReadAddr, NumOfBlocks) != HAL_OK)
  {
    sd_state = MSD_ERROR;
  }

  return sd_state;
}

/* USER CODE BEGIN BeforeWriteDMABlocksSection */
/* can be used to modify previous code / undefine following code / add code */
/* USER CODE END BeforeWriteDMABlocksSection */
/**
  * @brief  Writes block(s) to a specified address in an SD card, in DMA mode.
  * @param  pData: Pointer to the buffer that will contain the data to transmit
  * @param  WriteAddr: Address from where data is to be written
  * @param  NumOfBlocks: Number of SD blocks to write
  * @retval SD status
  */
__weak uint8_t BSP_SD_WriteBlocks_DMA(uint32_t *pData, uint32_t WriteAddr, uint32_t NumOfBlocks)
{
  uint8_t sd_state = MSD_OK;

  /* Write block(s) in DMA transfer mode */
  if (HAL_SD_WriteBlocks_DMA(&hsd, (uint8_t *)pData, WriteAddr, NumOfBlocks) != HAL_OK)
  {
    sd_state = MSD_ERROR;
  }

  return sd_state;
}

/* USER CODE BEGIN BeforeEraseSection */
/* can be used to modify previous code / undefine following code / add code */
/* USER CODE END BeforeEraseSection */
/**
  * @brief  Erases the specified memory area of the given SD card.
  * @param  StartAddr: Start byte address
  * @param  EndAddr: End byte address
  * @retval SD status
  */
__weak uint8_t BSP_SD_Erase(uint32_t StartAddr, uint32_t EndAddr)
{
  uint8_t sd_state = MSD_OK;

  if (HAL_SD_Erase(&hsd, StartAddr, EndAddr) != HAL_OK)
  {
    sd_state = MSD_ERROR;
  }

  return sd_state;
}

/**
  * @brief  Gets the current SD card data status.
  * @param  None
  * @retval Data transfer state.
  *          This value can be one of the following values:
  *            @arg  SD_TRANSFER_OK: No data transfer is acting
  *            @arg  SD_TRANSFER_BUSY: Data transfer is acting
  */
__weak uint8_t BSP_SD_GetCardState(void)
{
  return ((HAL_SD_GetCardState(&hsd) == HAL_SD_CARD_TRANSFER ) ? SD_TRANSFER_OK : SD_TRANSFER_BUSY);
}
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

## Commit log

2020-05-15 Adding files including - HAL driver from STM32Cube FW_F1 V1.8.0 - vs10xx files from master branch
2020-05-15 Move FreeRTOS tasks definitions to cubeMX and enable Dreq pin IRQ
2020-05-15 Add STemWin library files [BUG] There is wried compile error when I include "GUI.h" in main.c!
    [GUIConf.h, ili9340.c, main.c]
2020-05-17 Change MP3P.ioc file to generate Makefile based project. But required files for Keil are note removed. [BUG] There is error while running project. It seems CPU hangs after FreeRTOS is started. But sh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
    [MP3P.ioc]
2021-03-24 Change backbroud image - Fix bug in GUI.h by commention come QR definition - Use new mountain image for background - Unsuccessful try to use dialogs
    [main.c]
2021-03-26 Got working Dailog after bypassing FreeRTOS - Fix emWin timing issue by adding OS_TimeMS++ to TIM1 ISR - Add some widget to dialogbox
    [main.c]
2021-04-16 Trying to add ILI9486 support, but it's NOT possible. ILI9486 support only 666 color depth in SPI mode, but STemWin do not support 18bpp for GUIDRV_FLEXCOLOR_F66709. So I switch to ILI9340/ILI9341 ag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
2021-04-17 Working MP3P with a nice background - No framewin is used - Fonts are become smaller
2021-04-24 Some clean up - Add LCD-DTR Altium project - Add README.md file for better documentation - Add .gitignore to ignore unwanted Altium files
    [Interface.SchDoc, Interfaces.SchDoc, LCD-DTR-V1.00.PcbDoc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]
2021-04-25 Add remaining pin name of micro. Now there is no need to access schematic for firmware development
2021-04-25 Add BOM for LCD daughter board
2021-04-26 Add some new pictures for LCD-DTR board
2021-05-04 Add power-on / bl-on to ili9486_init()
2021-05-28 Semi working MP3 player with 3 tasks I'm not sure yet about problem, but I think it's timing.
    [MP3P.ioc, main.c, mp3_player.c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]
2021-06-04 Add precepio Tracealyzer
2021-06-06 [FIX] fix lwrb buffer corruption I did not check "LINEAR ADDREE LENGTH" wihle reading from buffer.
    [mp3_player.c]
2021-06-06 User GPIO externel interrupt callback for DREQ falling edge signal
2021-06-10 Add DAM1 channel#3 for SPI-Tx path
2021-06-10 Add macro for measureing execution time of SPI/f_read operation
2021-06-11 SPI-TX data is transferd via Channel#3 DAM
2021-06-11 Add DMA2 channel#4 for SDIO-RX [Update to STM32Cube_FW_F1_V1.8.4]
2021-06-18 Start/Stop LED blinking with playing mp3 file
2021-06-20 Add required files for Makefile build Note: Makefile build does NOT include Tracealyzer
2021-07-02 Enable EXTI for KEY[1,2,3] Enable SPI2_TX DMA to be used for STemWin
2021-07-02 Enable software timer of FreeRTOS Increase heap size to 10KiB
2021-07-04 Add timer callback to turn backligh off after 10s (if no button is pressed)
2021-07-09 [FIX] Increase vatask_hmi stack size which casue lots of error (configCHECK_FOR_STACK_OVERFLOW should be disable after development) for example: 1. configASSERT: ../Middlewares/Third_Party/FreeRTOS/S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
    [MP3P.ioc]
2021-07-09 Add BOX related files
    [holder.PcbDoc]
2021-07-16 Add box and it's conver files (ready to be printed)
    [box.PcbDoc, cover.PcbDoc]
2021-07-23 [BUG] Initial implementation of NEXT functionality via KEY3 After multiple pressing f_open() retures 18 which means FR_TOO_MANY_OPEN_FILES
    [hal_callbacks.c, main.c, mp3_player.c]
2021-08-11 Add debounce timer (which is not used yet)

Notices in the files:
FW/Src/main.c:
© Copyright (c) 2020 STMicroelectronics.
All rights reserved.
